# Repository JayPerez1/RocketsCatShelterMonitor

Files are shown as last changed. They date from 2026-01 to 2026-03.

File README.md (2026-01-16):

# Cat Shelter Monitor

Battery-powered temperature data logger to monitor temperatures and occupency in an outdoor feral cat shelter.

## Hardware (verified)
- Adafruit Feather nRF52840 Express
- DS3231 RTC + CR1220 backup
- 256KB SPI FRAM (CS = A1)
- 2x DS18B20 probes on 1-Wire (DATA = A2, external pull-up installed)
- 1S2P 18650 battery pack (not connected during bench testing)

## Firmware
- v1.0: Logging + BLE UART commands (STATUS / GETNEW / GETALL / CLEAR)

## Docs
- `docs/session-continuity.md`
- `docs/cat-shelter-chat-bootstrap.md`
- `docs/Cat_Shelter_BOM_v4.xlsx`

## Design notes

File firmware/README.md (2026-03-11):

# Cat Shelter Monitor Firmware

This folder contains firmware versions for the Cat Shelter Monitor project.

## Versions

### v1.1 – Current Development
Location:
firmware/CatShelterLogger_v1_1/

Features:
- BLE download support
- FRAM data logging
- RTC timestamping
- AMG8833 occupancy detection

### v1.0 – Legacy Version
Location:
firmware/CatShelterLogger_v1_0/

Earlier firmware used during early field testing.

## Hardware Platform

Board:
Adafruit nRF52840 Feather

Sensors:
- DS18B20 temperature sensors
- AMG8833 thermal array
- RTC
- FRAM

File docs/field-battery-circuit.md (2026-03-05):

# Cat Shelter Monitor — Field Battery Circuit (Final)

Battery packs are NOT charged in the field. Batteries are removed from the field enclosure,
charged in the office, and returned to the field.

The battery enclosure feeds the Feather through a 3 ft 2-wire cable into the Feather JST battery connector.

## Components inside battery enclosure

- 1-cell Li-ion battery
- Protection module (terminals: B+, B-, P+, P-)
- RUEF110 resettable PTC fuse (1.1A hold)
- On/Off switch
- 3 ft 22 AWG two-wire cable to Feather JST battery input

## Wiring

Battery → Protection board

Battery + → B+
Battery - → B-

Protected output → Feather

P+ → RUEF110 PTC → On/Off switch → Cable +
P- → Cable -

Cable + → JST +
Cable - → JST -

## Design Notes

- Protection board remains permanently connected to battery.
- Switch interrupts load only, not protection circuit.
- PTC fuse protects wiring and Feather from shorts.
- Cable shortened from 9 ft to 3 ft to reduce voltage drop.
- Wire gauge: 22 AWG.

## Field Check

Before connecting to the Feather:

Switch ON  
Measure voltage at JST connector

Red probe → JST +  
Black probe → JST -

Expected voltage: ~3.7–4.2 V

If voltage reads negative polarity is reversed.

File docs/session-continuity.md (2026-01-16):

# Session Continuity – Cat Shelter Monitor  
_Last updated: 2026-01-15_

## Project Overview
Battery-powered temperature data logger for an outdoor cat shelter.

- Logs **inside and outside temperature**
- Uses **FRAM for storage**
- **BLE download to phone**
- **CSV output**
- No field charging; batteries swapped indoors
- Target users are **non-technical**

---

## Hardware Status (COMPLETE & VERIFIED)

### Microcontroller
- Adafruit Feather nRF52840 Express

### Storage
- SPI FRAM 256KB
- CS pin: **A1**

### Timekeeping
- DS3231 RTC (I2C)
- CR1220 coin cell installed (RTC backup only)

### Sensors
- 2× DS18B20 waterproof probes
- Shared 1-Wire bus
- DATA pin: **A2**
- External pull-up resistor installed (DATA ? 3V)

### Power
- 1S2P 18650 battery pack
- Battery **not connected during bench testing**
- USB power verified
- Coin cell powers RTC only

### Wiring
- All wiring confirmed correct
- USB power test successful
- No electrical issues outstanding

---

## Software Status

### Firmware v1.0 (BASELINE – LOCKED)
- Logs temperature every **1 minute**
- Stores records in FRAM
- BLE UART commands:
  - `STATUS`
  - `GETNEW`
  - `GETALL`
  - `CLEAR`
- CSV format verified
- BLE + logging confirmed working end-to-end

### Known UX Issues in v1.0
- Generic BLE terminal required
- Manual copy/paste of scrolling text
- Buffer truncation in some apps
- Commands are non-intuitive for end users

These issues are **UX-related only**, not hardware or data integrity problems.

---

## GitHub / Version Control Status (IMPORTANT)

### Repository
- GitHub repo: `RocketsCatShelterMonitor`
- Remote correctly configured
- `main` branch is clean and synced

### Tags
- **v1.0** tag created and pushed  
  - Represents: *Hardware verified + original firmware behavior*

### Branching
- Active development branch:

---

## v1.1-ble-usability

- All future firmware changes must happen **only** on this branch

---

## Planned Improvements (v1.1 – NOT YET IMPLEMENTED)

Chosen improvement strategy:
- **Path 1 + Path 2**
- Self-guided BLE output
- Chunked CSV transfer

### v1.1 Design Goals
- Auto status/help text on BLE connect
- Replace multiple commands with a single user-facing command:

---

## Download

- Send **pure CSV only**
- Chunk output to avoid buffer overruns
- End with a clear marker:

---

## DOWNLOAD_COMPLETE,<sent>,<remaining>

- Keep logging interval at 1 minute
- Preserve all existing pin assignments

### Important Constraint
User is **not a programmer**.  
Any future code changes must be:
- One complete file
- Copy/paste only
- Exact file locations specified
- Step-by-step instructions, no assumptions

---

## Where to Resume Next Session

### First action tomorrow
1. Open this repository
2. Confirm you are on branch:

---

## v1.1-ble-usability

3. Provide the **current firmware HELP or STATUS output**
so the v1.1 code can be generated without guessing

### Next milestone
- Create `CatShelterLogger_v1_1.ino`
- Implement BLE usability improvements
- Commit as first v1.1 change
- Keep v1.0 untouched and recoverable

---

## Current State Summary
- Hardware: ? complete
- Firmware v1.0: ? working, tagged
- GitHub: ? clean, synced, recoverable
- UX improvements: ? planned, not yet started

Project is stable and ready to continue.

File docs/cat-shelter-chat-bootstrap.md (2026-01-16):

?? Session Continuity Summary – Outdoor Cat Shelter Monitoring Project
Project Goal

Build a battery-powered data logger to monitor inside and outside temperature of a stationary outdoor cat shelter, with phone-based data download and no field charging.

Locked Design Decisions
Power

Battery system: 1S2P using two 18650 cells (3.0–4.2 V)

Charging: Indoors only

Field unit: No charging circuitry

Batteries are swapped, not charged in the enclosure

USB port used only for programming/debug

Data & Operation

Logs temperature data continuously

Must store at least 7–10 days of data

Uses external FRAM for storage

BLE data download required from day one

Phone downloads only new data since last offload

Data saved as CSV, plain text

Sensors

2× waterproof DS18B20 temperature probes

One inside shelter

One outside shelter

Direct wiring (no JST/STEMMA requirement)

Environment

Northeast U.S. climate

Components sheltered from direct weather exposure

User Constraints

User is not a programmer

All instructions must be:

Exact step-by-step

No explanations unless explicitly requested

Any code must be:

Fully written

Exact cut-and-paste

With explicit file locations

BOM Rules

Adafruit first, Mouser second

Direct product URLs only

Plain Excel BOM

No formulas

No formatting

Raw values only

Final Hardware Selected (Prototype)
Microcontroller

Adafruit Feather nRF52840 Express (PID 4062)

BLE-first

No Wi-Fi required

Chosen specifically for reliable phone BLE downloads

Storage

Adafruit SPI FRAM 256KB (PID 4718)

Timekeeping

DS3231 RTC breakout (PID 3013)

CR1220 backup battery (PID 380)

Temperature Sensors

2× Adafruit waterproof DS18B20 probes (PID 381)

Includes required pull-up resistor

Power / Wiring

Switched JST-PH breakout (PID 1863)

Silicone ribbon cable (PID 6181)

User already has:

18650 batteries

Chargers

Heat shrink

Misc. connectors

Current Status

All prototype parts have been ordered from Adafruit

No assembly or software steps have been performed yet

Waiting for parts to arrive

Next Planned Steps (After Parts Arrive)

Inventory check

Exact wiring steps (one wire at a time)

Exact software installation steps

Firmware upload (provided fully written)

First power-on verification

BLE download test to phone

CSV file verification

Possible Interim Step (Optional, Before Parts Arrive)

Create a Git repository to:

Organize firmware

Store BOM and documentation

Back up project state

End of summary.

When you’re ready:

Start a new chat

Paste everything above

Say either:

“Parts arrived”, or

“Let’s set up the Git repo first”

We’ll pick up cleanly from there.

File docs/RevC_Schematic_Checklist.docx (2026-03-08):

Cat Shelter Monitor

Carrier Board Rev C — KiCAD Schematic Change Checklist

AMG8833 Thermal Camera Occupancy Sensor Addition

# Overview

This checklist documents all KiCAD schematic changes required to upgrade the Cat Shelter Monitor carrier board from Rev B to Rev C. The primary change is the addition of the Adafruit AMG8833 8x8 thermal camera sensor for cat occupancy detection.

The AMG8833 communicates via I2C and shares the existing I2C bus with the DS3231 RTC. The sensor will be mounted in a separate external enclosure connected via a STEMMA QT cable (JST-SH 4-pin 1.0mm) up to 24 inches in length.

## I2C Address Conflict Check

Confirm the following addresses are compatible before proceeding:

Device | I2C Address | Notes
DS3231 RTC | 0x68 | Fixed address.
AMG8833 Thermal Camera | 0x69 (default) | Can be changed to 0x68 by soldering Addr jumper — leave open (0x69).

- IMPORTANT: Do not solder the Addr jumper on the AMG8833 breakout board. Leave it open to maintain address 0x69.

# New Components to Add

Ref Des | Component | Value / Part | Notes
J_AMG1 | JST-SH 4-pin 1.0mm connector | JST SM04B-SRSS-TB or equivalent | STEMMA QT cable mates here. Bottom strip only — top strip is mechanical.

- The JST-SH connector pinout (looking into connector): pin 1 = GND, pin 2 = VCC, pin 3 = SDA, pin 4 = SCL on standard STEMMA QT cables. Verify against your specific cable before wiring.

# New Net Labels and Connections

Net Label | From | To | Notes
I2C_SDA | J_FEATHER_L1 (SDA pin) | J_AMG1 pin 4 | Shared with DS3231 RTC. No conflict — different I2C addresses.
I2C_SCL | J_FEATHER_L1 (SCL pin) | J_AMG1 pin 3 | Shared with DS3231 RTC. No conflict — different I2C addresses.
+3V3 | Feather 3V rail | J_AMG1 pin 1 | AMG8833 breakout has onboard 3.3V regulator. Feed 3.3V from Feather directly.
GND | Ground plane | J_AMG1 pin 2 | Common ground.
AMG_INT_D9 | J_AMG1 pin 5 (INT) | J_FEATHER_R1 (D9 pin) | Active low interrupt from AMG8833. D9 configured INPUT_PULLUP in firmware.

# Verification Checklist

Complete each item in order before sending the board for fabrication.

# | Check | Expected Result

1 | J_AMG1 connector added to schematic | JST-SH 4-pin 1.0mm, labeled J_AMG1
2 | J_AMG1 pin 1 connected to +3V3 net | Power to AMG8833 VIN
3 | J_AMG1 pin 2 connected to GND net | Common ground
4 | J_AMG1 pin 3 connected to I2C_SCL net | Shared SCL bus
5 | J_AMG1 pin 4 connected to I2C_SDA net | Shared SDA bus
6 | J_AMG1 pin 5 connected to AMG_INT_D9 net | INT signal from sensor
7 | AMG_INT_D9 net routed to J_FEATHER_R1 D9 pin | Interrupt to Feather
8 | AMG_INT_D9 label applied at both ends of net | Consistent net naming
9 | DS3231 I2C address confirmed 0x68 | No address conflict with AMG8833 at 0x69
10 | AMG8833 Addr jumper confirmed unsoldered | AMG8833 at 0x69
11 | Run ERC in KiCAD — no new errors | Clean ERC pass
12 | Run netlist check — all new nets connected | No unconnected pins on J_AMG1
13 | Update schematic title block to Rev C | Revision history reflects changes
14 | Add J_AMG1 to BOM | Component captured for procurement

# Associated Firmware Changes

The following firmware changes have already been implemented in CatShelterLogger_v1_2.ino and platformio.ini. They are noted here for reference only — no additional firmware work is required before fabrication.

- Added adafruit/Adafruit AMG88xx@^1 to platformio.ini lib_deps
- AMG8833 initialized on I2C in setup()
- D9 configured as INPUT_PULLUP for INT pin
- Occupancy detection: pixel deviation from scene average in either direction (handles hot cat in cool shelter and cool cat in hot shelter)
- Cat count estimation via flood-fill blob detection on 8x8 pixel grid
- Rate-of-Rise (RoR) calculation on internal DS18B20 probe — 4-sample rolling window
- Two-factor occupancy: OR logic during testing (change to AND after threshold tuning)
- Pixel stats (min, max, avg) stored in each CSV record for post-analysis
- New THERMAL BLE command for real-time raw pixel dump during field tuning
- Updated Record struct — MAGIC bumped to prevent v1.1 FRAM data misread
- Updated CSV header: datetime, t0C, t1C, occupied, cats, pix_min, pix_max, pix_avg

# Field Tuning Notes

The following compile-time constants in CatShelterLogger_v1_2.ino will require tuning based on real-world testing. Use the THERMAL BLE command to observe raw pixel values before adjusting.

- AMG_DEVIATION_THRESHOLD (default 4.0°C) — minimum pixel deviation from scene average to be considered a hot/cold spot
- AMG_MIN_BLOB_PIXELS (default 3) — minimum connected pixels to count as one cat
- ROR_THRESHOLD_C_PER_MIN (default 0.5°C/min) — rate of rise threshold on internal probe
- ROR_WINDOW_SIZE (default 4 samples) — at 30s interval = 2 min history; at 3min interval = 12 min history — may need reducing for deployed interval
- After initial tuning, change occupancy detection logic from OR to AND in detectOccupancy() for reduced false positives.

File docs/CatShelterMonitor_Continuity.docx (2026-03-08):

Rockets Cat Shelter Monitor

Project Continuity Document

Generated: March 2026

GitHub: https://github.com/JayPerez1/RocketsCatShelterMonitor

Purpose: Provide full project context to resume work in a future AI session or hand off to another developer.

# 1. Project Overview

The Rockets Cat Shelter Monitor is a battery-powered IoT system for monitoring feral cat shelters in urban and suburban backyards in the Northeast USA. The system collects temperature and occupancy data, stores it locally, and transfers it to a mobile phone via Bluetooth Low Energy (BLE) for export as CSV/Excel.

The project is organized in two phases:

- Phase 1 (complete): Temperature monitoring using two DS18B20 waterproof probes — one inside, one outside the shelter.
- Phase 2 (in progress): Occupancy detection using an AMG8833 8x8 thermal camera sensor, with Rate-of-Rise compensation to reduce false positives.

Deployment environment: 2'x2'x1.5' insulated wood and dense foam shelters, single entry point, no WiFi, no solar power, northeast USA.

# 2. Hardware

Component | Part # | Status | Notes
Adafruit Feather nRF52840 | #4062 | In use | Main MCU. nRF52840, BLE, 1MB Flash, 256KB RAM, 64MHz Cortex-M4.
DS18B20 Waterproof Temp Sensor (x2) | #381 | In use | One-Wire bus on pin A2. 4.7kΩ pull-up. Probe 0 = inside shelter, Probe 1 = outside.
Adafruit FRAM SPI | — | NOT working — Rev A/B PCB error | Corrected in Rev B KiCAD schematic. CS on D10.
DS3231 RTC | — | NOT working — Rev A/B PCB error | Corrected in Rev B KiCAD schematic. I2C address 0x68.
Adafruit AMG8833 8x8 Thermal Camera | #3538 (STEMMA QT) | PLANNED — Rev C | I2C address 0x69. INT on D9. External enclosure, 18-24" STEMMA QT cable.
18650 Li-Ion Cell (x1) | — | In use | 5+ day battery life tested.
Custom Carrier PCB | Rev B (corrected, not fabricated) | PENDING fabrication | Rev C will incorporate AMG8833 connector.

## 2.1 Pin Assignments

Pin | Net / Signal | Connected To
A2 | A2_1WIRE | DS18B20 One-Wire bus (both probes). 4.7kΩ pull-up to 3.3V.
D10 | FRAM_CS_D10 | FRAM SPI chip select.
SCK | SPI_SCK | FRAM SPI clock.
MO | SPI_MOSI | FRAM SPI MOSI.
MI | SPI_MISO | FRAM SPI MISO.
SDA | I2C_SDA | DS3231 RTC (0x68). AMG8833 thermal camera (0x69) — Rev C.
SCL | I2C_SCL | DS3231 RTC (0x68). AMG8833 thermal camera (0x69) — Rev C.
D9 | AMG_INT_D9 | AMG8833 INT pin (active low). Configured INPUT_PULLUP in firmware. — Rev C.
A0, A1, A3, A4, A5, D5, D6, D11, D12, D13, D2 | Available | Unconnected. Available for future use.

## 2.2 I2C Bus

- DS3231 RTC: address 0x68
- AMG8833 Thermal Camera: address 0x69 (default — Addr jumper must remain unsoldered)
- No address conflict. Both devices share SDA/SCL.
- Cable to AMG8833: 18-24" STEMMA QT (JST-SH 4-pin 1.0mm). I2C at 100kHz over this length requires testing and may need pull-up tuning.

## 2.3 PCB Status

- Rev A: Original fabricated board. FRAM and RTC had wiring errors — non-functional.
- Rev B: Corrections made in KiCAD schematic. Not yet fabricated.
- Rev C: Rev B corrections + AMG8833 JST-SH connector + AMG_INT_D9 net. Target for fabrication. See RevC_Schematic_Checklist.docx for full change list.

# 3. Firmware

File | Version | Notes
CatShelterLogger_v1_1.ino | v1.1 | Phase 1 — temperature only. Currently deployed. Saved to GitHub before v1.2 changes.
CatShelterLogger_v1_2.ino | v1.2 | Phase 2 — adds AMG8833 occupancy detection, RoR, THERMAL BLE command. PENDING hardware.
platformio.ini | v1.2 | Adds adafruit/Adafruit AMG88xx@^1 to lib_deps.

## 3.1 Key Architecture Decisions

- Framework: Arduino via PlatformIO.
- Storage: FRAM primary (when working). RAM-only fallback when FRAM unavailable — currently active since FRAM not yet functional on Rev A/B hardware.
- Time base: Set via SETUNIX BLE command from phone. RTC not yet functional — firmware maintains soft clock from phone-set Unix timestamp.
- BLE: Nordic UART Service (NUS) via Adafruit Bluefruit library. Device name 'CatSh'. Self-guides user with welcome banner and HELP command on connect.
- CSV download: Chunked with small delays (3ms per line, 20ms yield every 25 lines) to avoid BLE buffer overflow.

## 3.2 BLE Commands

Command | Version | Description
HELP | v1.1+ | Lists all available commands.
STATUS | v1.1+ | Reports firmware build, write_index, last_sent_index, max_records, record size, fram_ok, rtc_ok, ram_only, amg_ok, current RoR, RoR sample count.
SETUNIX <unix_seconds> | v1.1+ | Sets the time base from phone Unix timestamp. Used since RTC is not yet working.
DOWNLOAD | v1.1+ | Downloads CSV records since last_sent_index. Updates last_sent_index on completion.
DOWNLOADALL | v1.1+ | Downloads all CSV records from index 0.
THERMAL | v1.2 | Dumps current 8x8 AMG8833 pixel array. Reports scene avg, min, max, current RoR, then rows R0-R7. Use for field tuning of threshold constants.
CLEAR | v1.1+ | Resets write_index and last_sent_index. Clears RoR window in v1.2.

## 3.3 CSV Output Format (v1.2)

Column | Version | Description
datetime | v1.1+ | MM/DD HH:MM. UTC-5 (EST). No DST adjustment.
t0C | v1.1+ | Inside shelter temperature in °C (rounded integer).
t1C | v1.1+ | Outside shelter temperature in °C (rounded integer).
occupied | v1.2 | 0 = unoccupied, 1 = occupied. Two-factor: thermal blob OR RoR trigger (change to AND after tuning).
cats | v1.2 | Estimated cat count 0-4 from blob detection.
pix_min | v1.2 | Minimum pixel temperature in °C from AMG8833 frame.
pix_max | v1.2 | Maximum pixel temperature in °C from AMG8833 frame.
pix_avg | v1.2 | Average pixel temperature in °C from AMG8833 frame.

## 3.4 Occupancy Detection Algorithm

The algorithm uses two independent factors combined with OR logic during initial testing (to be changed to AND after tuning):

Factor 1 — Thermal Blob Detection (AMG8833):

- Read all 64 pixels from the 8x8 array.
- Calculate scene average temperature.
- Flag pixels that deviate from the average by more than AMG_DEVIATION_THRESHOLD in either direction. This handles both cool-weather scenarios (cat warmer than shelter) and summer scenarios (cat cooler than hot shelter interior).
- Use 4-connectivity flood fill to identify connected blobs of deviant pixels.
- Blobs smaller than AMG_MIN_BLOB_PIXELS are discarded as noise.
- Remaining blob count = estimated cat count (capped at AMG_MAX_CATS).

Factor 2 — Rate-of-Rise on Internal Probe (DS18B20 probe 0):

- Maintain a rolling window of ROR_WINDOW_SIZE temperature samples.
- Calculate RoR = (newest - oldest) / time_span in °C/minute.
- Absolute value is used — handles both warming entry and cooling entry into hot summer shelter.
- If |RoR| exceeds ROR_THRESHOLD_C_PER_MIN, it indicates animal entry event.
- Slow solar heating of insulated shelter produces drift well below this threshold. Analogous to commercial RoR fire detectors used in attics.

## 3.5 Tuning Constants

All tuning constants are compile-time defines at the top of CatShelterLogger_v1_2.ino. Use the THERMAL BLE command to observe real field values before adjusting.

Constant | Default | Notes
AMG_DEVIATION_THRESHOLD | 4.0°C | Minimum pixel deviation from scene average (either direction) to flag as hot/cold spot. Handles both cool-weather and summer scenarios.
AMG_MIN_BLOB_PIXELS | 3 pixels | Minimum connected pixels to count as one cat blob.
AMG_MAX_CATS | 4 | Maximum reported cat count.
ROR_WINDOW_SIZE | 4 samples | Rolling window for RoR calculation. At 30s interval = 2 min history. At 3min deployed interval = 12 min — may need reducing.
ROR_THRESHOLD_C_PER_MIN | 0.5°C/min | Absolute RoR threshold on internal probe. Handles both entry (warming) and entry-into-hot-shelter (cooling).
LOG_INTERVAL_MS | 30,000ms | 30 seconds for dev/test. Change to 180,000ms (3 min) for deployment.

# 4. Key Design Decisions and Rationale

Decision | Rationale
AMG8833 thermal camera selected over PIR, IR beam break, VL53L0X ToF | PIR detects only motion, not stationary sleeping cats. IR beam break only detects entry/exit. VL53L0X detects entry only. AMG8833 can detect stationary presence and estimate multiple occupants via blob detection.
STEMMA QT version of AMG8833 selected | JST-SH 4-pin keyed connector eliminates wiring errors on 18-24" cable run. No soldering required on sensor side.
D9 selected for AMG8833 INT pin | Not currently used in schematic. No documented restrictions on nRF52840 Feather. Supports interrupts. D2 is restricted (NFC pad). D7 is onboard tactile switch. D3 is onboard red LED.
Rate-of-Rise (RoR) on internal DS18B20 added as second occupancy factor | Insulated shelter changes temperature slowly due to environmental factors. Animal entry causes rapid change. RoR is direction-agnostic — handles both cool-weather entry (warming) and summer entry (cooling). Analogous to commercial fire alarm RoR detectors in attics.
OR logic for occupancy during initial testing | Allows independent observation of both thermal blob detection and RoR in CSV data before committing to AND logic. Change to AND after threshold tuning is complete.
Pixel stats (min, max, avg) stored in every record | Provides historical context for post-analysis without requiring a live BLE connection. Enables algorithm performance review from downloaded CSV.
THERMAL BLE command added | Allows real-time observation of raw 8x8 pixel values in the field. Essential for informed threshold tuning rather than guessing.
Record MAGIC bumped to CSLH for v1.2 | Record struct size changed (new fields added). Different MAGIC prevents v1.1 FRAM data from being misread as valid v1.2 data.
I2C shared bus for RTC and AMG8833 | DS3231 at 0x68, AMG8833 at 0x69 — no address conflict. AMG8833 Addr jumper must remain unsoldered. I2C cable length up to 24" at 100kHz requires testing.

# 5. Open Items and Next Steps

Items are listed in recommended sequence. Items 4 and 10 have no dependencies and can be done immediately.

# | Item | Detail | Dependency

1 | Fabricate Rev C carrier PCB | Incorporate all Rev B corrections plus AMG8833 JST-SH connector and AMG_INT_D9 net. See RevC_Schematic_Checklist.docx. | KiCAD schematic Rev C complete
2 | Verify STEMMA QT cable pinout | Confirm pin 1 orientation on the specific cable purchased before PCB layout is finalized. | Cable selection
3 | Test I2C reliability over 18-24" cable | At 100kHz. May require pull-up resistor tuning based on cable capacitance. Test before committing to cable length. | Rev C hardware
4 | Prototype AMG8833 on breadboard | Wire to Feather via breadboard before Rev C PCB arrives. Verify sensor reads correctly and THERMAL BLE command works. | None — can do now
5 | Field-tune occupancy thresholds | Use THERMAL BLE command to observe real pixel values. Adjust AMG_DEVIATION_THRESHOLD, AMG_MIN_BLOB_PIXELS, ROR_THRESHOLD_C_PER_MIN, ROR_WINDOW_SIZE. | Prototype working
6 | Switch occupancy logic from OR to AND | In detectOccupancy() — line marked with comment. Do this after thresholds are tuned and false positive rate is acceptable. | Field tuning complete
7 | Verify FRAM and RTC on Rev C board | Both were non-functional on Rev A/B due to PCB errors. Rev B corrections are in KiCAD but untested on physical hardware. | Rev C hardware
8 | Adjust LOG_INTERVAL_MS for deployment | Change from 30,000ms (30s) to 180,000ms (3 min) in firmware. Also re-evaluate ROR_WINDOW_SIZE at 3-min interval. | Field testing
9 | DST handling in CSV timestamps | Current firmware applies fixed UTC-5 offset (EST). No DST adjustment. Consider adding DST handling for spring/summer accuracy. | Optional enhancement
10 | Update GitHub after Rev C firmware changes | Save v1.2 firmware and updated platformio.ini to GitHub. Repository: https://github.com/JayPerez1/RocketsCatShelterMonitor | None — do before hardware work

# 6. Repository and File Reference

## 6.1 GitHub

- URL: https://github.com/JayPerez1/RocketsCatShelterMonitor
- State at session end: v1.1 firmware and existing files saved to GitHub before v1.2 changes were written.
- Next commit should include: CatShelterLogger_v1_2.ino and updated platformio.ini.

## 6.2 Key Files

- CatShelterLogger_v1_1.ino — Phase 1 firmware (temperature only). Baseline.
- CatShelterLogger_v1_2.ino — Phase 2 firmware (occupancy detection). Written but not yet deployed to hardware.
- platformio.ini — Build configuration. v1.2 adds Adafruit AMG88xx library.
- CatShelterMonitor_Carrier-RevB.kicad_sch — Corrected schematic (Rev B). Not yet fabricated. Basis for Rev C.
- RevC_Schematic_Checklist.docx — Complete checklist of KiCAD changes required for Rev C PCB.

## 6.3 Uploaded Reference Documents (from this session)

- adafruit-amg8833-8x8-thermal-camera-sensor.pdf — Adafruit AMG8833 learn guide. Confirms I2C address 0x69, pinout, library name, 10K pull-ups on breakout board.
- introducing-the-adafruit-nrf52840-feather.pdf — Feather nRF52840 guide. Confirms D9 has no restrictions. D2 is NFC pad (avoid). D7 is tactile switch. D3 is red LED.

# 7. How to Resume in a New AI Session

To bring a new AI assistant up to speed quickly, provide the following in order:

- Share this document.
- Share RevC_Schematic_Checklist.docx.
- Upload CatShelterLogger_v1_2.ino and platformio.ini.
- Upload CatShelterMonitor_Carrier-RevB.kicad_sch if schematic work is needed.
- State which open item from Section 5 you want to work on next.

The AI will not need the full chat transcript if this document is provided. All critical decisions, rationale, hardware details, firmware architecture, and open items are captured here.

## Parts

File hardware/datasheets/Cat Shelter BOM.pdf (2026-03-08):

Sort | Item | Category | Supplier | Supplier SKU | Manufacturer | MPN | Buy Qty | Buy Price | Need Qty | Per Unit | Ext. Price
1 | Microcontroller board (BLE-first) | Compute | Adafruit | 4062 | Adafruit Industries | 4062 | 1 | $24.95 | 1 | $24.95 | $24.95
2 | Non-volatile memory (SPI FRAM 256KB) | Data Storage | Adafruit | 4718 | Fujitsu | MB85RS2MTA | 1 | $12.95 | 1 | $12.95 | $12.95
3 | Precision RTC breakout (I2C) | Timekeeping | Adafruit | 3013 | Analog Devices / Maxim | DS3231 | 1 | $17.50 | 1 | $17.50 | $17.50
4 | Coin cell for RTC backup | Timekeeping | Adafruit | 380 | Various (verified by Adafruit) CR1220 | | 1 | $0.95 | 1 | $0.95 | $0.95
5 | Waterproof temperature probe (DS18B20) | Sensing | Adafruit | 381 | Maxim / Analog Devices | DS18B20 | 1 | $9.95 | 2 | $9.95 | $19.90
6 | AMG8833 IR Thermal Camera | Sensing | Adafruit | 3538 | Adafruit Industries | 3538 | 1 | $44.95 | 1 | $44.95 | $44.95
7 | Custom Circuit Board v1.0 (Protoype) | Circuit Board | OSH Park | aE27EfQZ | OSH Park | | 3 | $49.25 | 1 | $16.42 | $16.42
7 | Custom Circuit Board v2.0 (Add Camera) | Circuit Board | OSH Park | KNqJMJn5 | OSH Park | | 3 | $59.25 | 0 | $19.75 | $0.00
8 | CABLE ASSY JST PH 2 PIN 4" | Circuit Board | DigiKey | 1528-261-ND | Adafruit Industries | 261 | 2 | $1.50 | 2 | $0.75 | $1.50
9 | 3W, 3.5MM PITCH TERM-BLOCK, ANGLED | Circuit Board | DigiKey2073-TBD05-03-1-G-G-NDGCT | | | TBD05-03-1-G-G | 10 | $8.84 | 2 | $0.88 | $1.77
10 | PTC RESET FUSE 30V 1.1A RADIAL | Circuit Board | DigiKey | RUEF110HF-ND | Littelfuse Inc. | RUEF110 | 5 | $2.00 | 1 | $0.40 | $0.40
11 | 18650 Lithium-Ion Battery | Power | | | | | 1 | $0.00 | 1 | $0.00 | $0.00
12 | 18650 Lithium-Ion Battery Holder | Power (Outdoor) | Amazon | B09LC681XX | Aobao | AB- Battery Holder | 5 | $10.79 | 1 | $2.16 | $2.16
13 | Litium-Ion BMS Protection Board | Power (Outdoor) | eBay | | ovo-trend-seller | | 5 | $14.34 | 1 | $2.87 | $2.87
14 | Mini Rocker Switch | Power (Outdoor) | eBayKG-15mm-HX15cm-2P-Hei-5 YuanXing | | | | 5 | $11.61 | 1 | $2.32 | $2.32
15 | ATO blade fuse, 2A | Power (Outdoor) | Mouser | 576-0ATO002.V | Littelfuse | 0ATO002.V | 5 | $1.24 | 1 | $0.25 | $0.25
16 | PG-7 Cable Glands | Enclosure | eBay | 225FWY | | | 10 | $11.87 | 5 | $1.19 | $5.94
17 | 22 AWG Silicone Wire - 20ft (Black & Red) | Wiring | eBay | | | | 20 | $9.22 | 10 | $0.46 | $4.61
18 | Break-Away Male Header Strip | Prototyping | Amazon | 16P16-2.54-30 | Antrader | B07GP3TLH9 | 30 | $7.55 | 4 | $0.25 | $1.01
19 | Circuit Board Enclosure | Consumables | 3D Printer | | | | 3 | $3.00 | 1 | $1.00 | $1.00
20 | Charger Station Enclosure | Consumables | 3D Printer | | | | 3 | $3.00 | 1 | $1.00 | $1.00
21 | Field Battery Enclosure | Consumables | 3D Printer | | | | 3 | $3.00 | 1 | $1.00 | $1.00
22 | Infrared Camera Enclosure | Consumables | 3D Printer | | | | 1 | $1.00 | 1 | $1.00 | $1.00
23 | Multi-colored heat shrink pack | Consumables | Adafruit | 1649 | Adafruit Industries | 1649 | 1 | $4.95 | 1 | $4.95 | $4.95
24 | UPS Ground | Shipping | UPS | | | | | $35.00 | | | $25.00
Total Amount Spent | $348.66 | $194.38
Amount in Inventory | $154.28

8 | USB-C LiIon/LiPoly charger (desk charger) | Power (Indoor) | Adafruit | 4410 | Adafruit Industries | 4410 | 5 | $5.95 | 0 | $1.19 | $0.00
| 3W, 3.5MM PITCH TERM-BLOCK, SIDE | Circuit Board | DigiKey | -TAD05-03-1-L-G-ND | | TAD05-03-1-L-G | 1 | $0.43 | 0 | $0.43 | $0.00

Direct Product URL | Status | Lead/Risk Notes
https://www.adafruit.com/product/4062 | Required | BLE required; Micro-USB for programming.
https://www.adafruit.com/product/4718 | Recommended | 256KB FRAM provides weeks of logs.
https://www.adafruit.com/product/3013 | Recommended | Add CR1220 backup battery for time retention.
https://www.adafruit.com/product/380 | Recommended | Lithium shipping restrictions may apply.
https://www.adafruit.com/product/381 | Required | Waterproof probe; Includes 4.7k pull-up resistor.
https://www.adafruit.com/product/6181 | Required
https://oshpark.com/orders/KNqJMJn5 | Required
https://oshpark.com/orders/KNqJMJn5 | Required
https://www.digikey.com/en/products/detail/adafruit-industries-llc/261/5353586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 Required https://www.digikey.com/en/products/detail/gct/TBD05-03-1-G-G/26408887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 Required
| Required | Recovered from Ryobi 40v, 6amp Battery Pack.
https://www.amazon.com/dp/B09LC681XX?ref=ppx_yo2ov_dt_b_fed_asin_title | Required
ovo-trend-seller | Required
5Pcs Mini round Rocker Switch 15Mm on off Latching Toggle Switch SPST 2Pin 6A 12 | eBay | Required
https://www.mouser.com/ProductDetail/Littelfuse/0ATO002.V | Required | Spare fuses recommended.
https://www.ebay.com/itm/222447428743 | Required | Sized for 0.118"–0.169" cable diameter.
https://www.ebay.com/itm/198037457213 | Required | Flexible in cold; good for internal harnessing.
https://www.amazon.com/dp/B07GP3TLH9?ref=ppx_yo2ov_dt_b_fed_asin_title&th=1 | Required | 2.54mm 16 Pin Single Row PBC Female Pin Header.
https://www.adafruit.com/product/1649 | Recommended | Strain relief + labeling.
Shipping UPS Ground | Required
Total for 1st Board

https://www.adafruit.com/product/4410 | Required | Used indoors only.

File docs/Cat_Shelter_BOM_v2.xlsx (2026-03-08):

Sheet: BOM
Sort | Item | Category | Supplier | Supplier SKU | Manufacturer | MPN | Buy Qty | Buy Price | Need Qty | Per Unit | Ext. Price | Direct Product URL | Status | Lead/Risk Notes
1 | Microcontroller board (BLE-first) | Compute | Adafruit | 4062 | Adafruit Industries | 4062 | 1 | $24.95 | 1 | $24.95 | $24.95 | https://www.adafruit.com/product/4062 | Required | BLE required; Micro-USB for programming.
2 | Non-volatile memory (SPI FRAM 256KB) | Data Storage | Adafruit | 4718 | Fujitsu | MB85RS2MTA | 1 | $12.95 | 1 | $12.95 | $12.95 | https://www.adafruit.com/product/4718 | Recommended | 256KB FRAM provides weeks of logs.
3 | Precision RTC breakout (I2C) | Timekeeping | Adafruit | 3013 | Analog Devices / Maxim | DS3231 | 1 | $17.50 | 1 | $17.50 | $17.50 | https://www.adafruit.com/product/3013 | Recommended | Add CR1220 backup battery for time retention.
4 | Coin cell for RTC backup | Timekeeping | Adafruit | 380 | Various (verified by Adafruit) | CR1220 | 1 | $0.95 | 1 | $0.95 | $0.95 | https://www.adafruit.com/product/380 | Recommended | Lithium shipping restrictions may apply.
5 | Waterproof temperature probe (DS18B20) | Sensing | Adafruit | 381 | Maxim / Analog Devices | DS18B20 | 1 | $9.95 | 2 | $9.95 | $19.90 | https://www.adafruit.com/product/381 | Required | Waterproof probe; Includes 4.7k pull-up resistor.
6 | AMG8833 IR Thermal Camera | Sensing | Adafruit | 3538 | Adafruit Industries | 3538 | 1 | $44.95 | 1 | $44.95 | $44.95 | https://www.adafruit.com/product/6181 | Required
7 | Custom Circuit Board v1.0 (Protoype) | Circuit Board | OSH Park | aE27EfQZ | OSH Park |  | 3 | $49.25 | 1 | $16.42 | $16.42 | https://oshpark.com/orders/KNqJMJn5 | Required
7 | Custom Circuit Board v2.0 (Add Camera) | Circuit Board | OSH Park | KNqJMJn5 | OSH Park |  | 3 | $59.25 | 0 | $19.75 | $0.00 | https://oshpark.com/orders/KNqJMJn5 | Required
8 | CABLE ASSY JST PH 2 PIN 4" | Circuit Board | DigiKey | ‎1528-261-ND‎ | Adafruit Industries | 261‎ | 2 | $1.50 | 2 | $0.75 | $1.50 | https://www.digikey.com/en/products/detail/adafruit-industries-llc/261/5353586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 | Required
9 | 3W, 3.5MM PITCH TERM-BLOCK, ANGLED | Circuit Board | DigiKey | 2073-TBD05-03-1-G-G-ND | GCT | ‎TBD05-03-1-G-G‎ | 10 | $8.84 | 2 | $0.88 | $1.77 | https://www.digikey.com/en/products/detail/gct/TBD05-03-1-G-G/26408887?_gl=1*hqzd1z*_up*MQ..&gclsrc=3p.ds | Required
10 | PTC RESET FUSE 30V 1.1A RADIAL | Circuit Board | DigiKey | ‎RUEF110HF-ND‎ | Littelfuse Inc. | RUEF110‎ | 5 | $2.00 | 1 | $0.40 | $0.40
11 | 18650 Lithium-Ion Battery | Power |  |  |  |  | 1 | $0.00 | 1 | $0.00 | $0.00 |  | Required | Recovered from Ryobi 40v, 6amp Battery Pack.
12 | 18650 Lithium-Ion Battery Holder | Power (Outdoor) | Amazon | B09LC681XX | Aobao | AB- Battery Holder | 5 | $10.79 | 1 | $2.16 | $2.16 | https://www.amazon.com/dp/B09LC681XX?ref=ppx_yo2ov_dt_b_fed_asin_title | Required
13 | Litium-Ion BMS Protection Board | Power (Outdoor) | eBay |  | ovo-trend-seller |  | 5 | $14.34 | 1 | $2.87 | $2.87 | ovo-trend-seller | Required
14 | Mini Rocker Switch | Power (Outdoor) | eBay | KG-15mm-HX15cm-2P-Hei-5 | YuanXing |  | 5 | $11.61 | 1 | $2.32 | $2.32 | 5Pcs Mini round Rocker Switch 15Mm on off Latching Toggle Switch SPST 2Pin 6A 12 | eBay (https://www.ebay.com/itm/226886814060) | Required
15 | ATO blade fuse, 2A | Power (Outdoor) | Mouser | 576-0ATO002.V | Littelfuse | 0ATO002.V | 5 | $1.24 | 1 | $0.25 | $0.25 | https://www.mouser.com/ProductDetail/Littelfuse/0ATO002.V | Required | Spare fuses recommended.
16 | PG-7 Cable Glands | Enclosure | eBay | 225FWY |  |  | 10 | $11.87 | 5 | $1.19 | $5.93 | https://www.ebay.com/itm/222447428743 | Required | Sized for 0.118"–0.169" cable diameter.
17 | 22 AWG Silicone Wire - 20ft (Black & Red) | Wiring | eBay |  |  |  | 20 | $9.22 | 10 | $0.46 | $4.61 | https://www.ebay.com/itm/198037457213 | Required | Flexible in cold; good for internal harnessing.
18 | Break-Away Male Header Strip | Prototyping | Amazon | 16P16-2.54-30 | Antrader | B07GP3TLH9 | 30 | $7.55 | 4 | $0.25 | $1.01 | https://www.amazon.com/dp/B07GP3TLH9?ref=ppx_yo2ov_dt_b_fed_asin_title&th=1 | Required | 2.54mm 16 Pin Single Row PBC Female Pin Header.
19 | Circuit Board Enclosure | Consumables | 3D Printer |  |  |  | 3 | $3.00 | 1 | $1.00 | $1.00
20 | Charger Station Enclosure | Consumables | 3D Printer |  |  |  | 3 | $3.00 | 1 | $1.00 | $1.00
21 | Field Battery Enclosure | Consumables | 3D Printer |  |  |  | 3 | $3.00 | 1 | $1.00 | $1.00
22 | Infrared Camera Enclosure | Consumables | 3D Printer |  |  |  | 1 | $1.00 | 1 | $1.00 | $1.00
23 | Multi-colored heat shrink pack | Consumables | Adafruit | 1649 | Adafruit Industries | 1649 | 1 | $4.95 | 1 | $4.95 | $4.95 | https://www.adafruit.com/product/1649 | Recommended | Strain relief + labeling.
24 | UPS Ground | Shipping | UPS |  |  |  |  | $35.00 |  |  | $25.00 | Shipping UPS Ground | Required
 |  |  |  |  |  |  | Total Amount Spent | $348.66 |  |  | $194.38 | Total for 1st Board
 |  |  |  |  |  |  | Amount in Inventory | $154.28
8 | USB-C LiIon/LiPoly charger (desk charger) | Power (Indoor) | Adafruit | 4410 | Adafruit Industries | 4410 | 5 | $5.95 | 0 | $1.19 | $0.00 | https://www.adafruit.com/product/4410 | Required | Used indoors only.
 | 3W, 3.5MM PITCH TERM-BLOCK, SIDE | Circuit Board | DigiKey | ‎2073-TAD05-03-1-L-G-ND‎ |  | ‎TAD05-03-1-L-G‎ | 1 | $0.43 | 0 | $0.43 | $0.00

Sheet: Locked Decisions
Outdoor Cat Shelter Monitoring – Locked Decisions
Temperature probes: use Adafruit DS18B20 waterproof probes; pull-up resistor included (no separate resistor purchase needed).
Power
• Charging indoors only; no charging circuitry in field unit.
• Field operation uses swappable battery packs.
• Battery: 1S2P using 18650 cells (3.0–4.2 V system).
• USB-C is retained only for programming/debugging (not charging).
• NOTE: Selected Feather nRF52840 uses Micro-USB for programming; functionally equivalent to USB-C for this project.
Communications / Data Offload
• BLE offload to a phone is required from day one; app should download only new records since last offload.
Sensors / Connectors
• Waterproof temperature sensing required.
• DS18B20 waterproof probe acceptable.
• Connector requirement dropped; direct wiring is fine.
• Components tolerate Northeast US climate; sheltered from direct weather.
Suppliers / BOM Rules
• Prefer Adafruit first, Mouser second.
• BOM must use direct product links to unique SKUs (no search/category links).
• Include exact part numbers (MPNs), quantities, and flag long-lead/risk items.

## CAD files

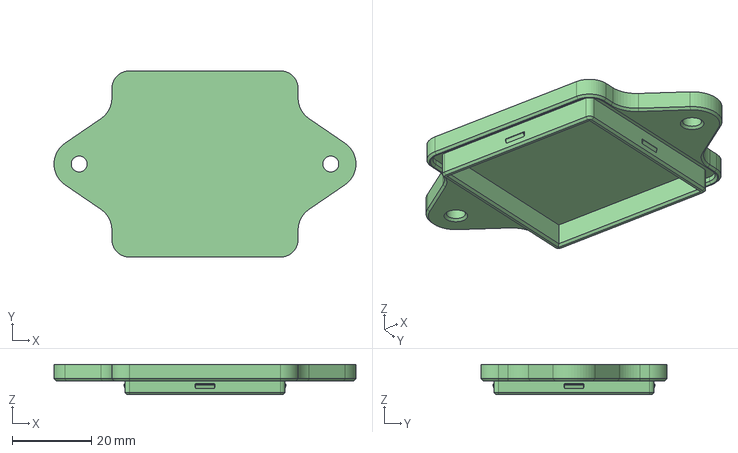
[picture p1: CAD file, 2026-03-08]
hardware/enclosure/AMG8833_Housing_Body - Cover.step
76.2 x 47.0 x 7.62 mm

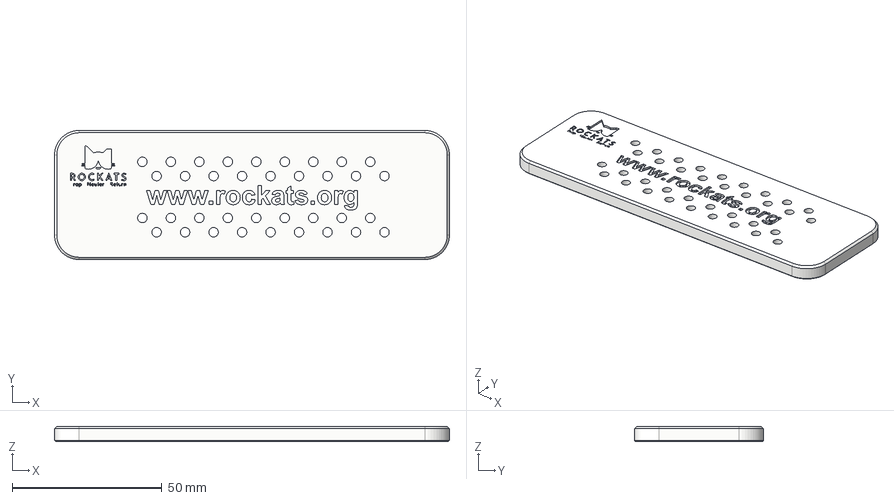
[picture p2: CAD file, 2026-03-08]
hardware/enclosure/Battery Charging Enclosure - Cover.step
132.1 x 43.2 x 5.08 mm
Charger Circuit Board
Battery Office Enclosure - Cover

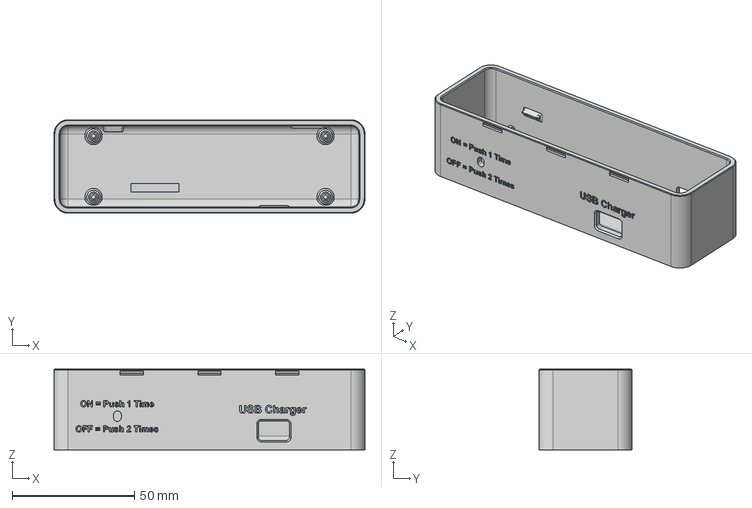
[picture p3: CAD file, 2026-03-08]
hardware/enclosure/Battery Charging Enclosure - Bottom.step
127.0 x 38.1 x 33.0 mm

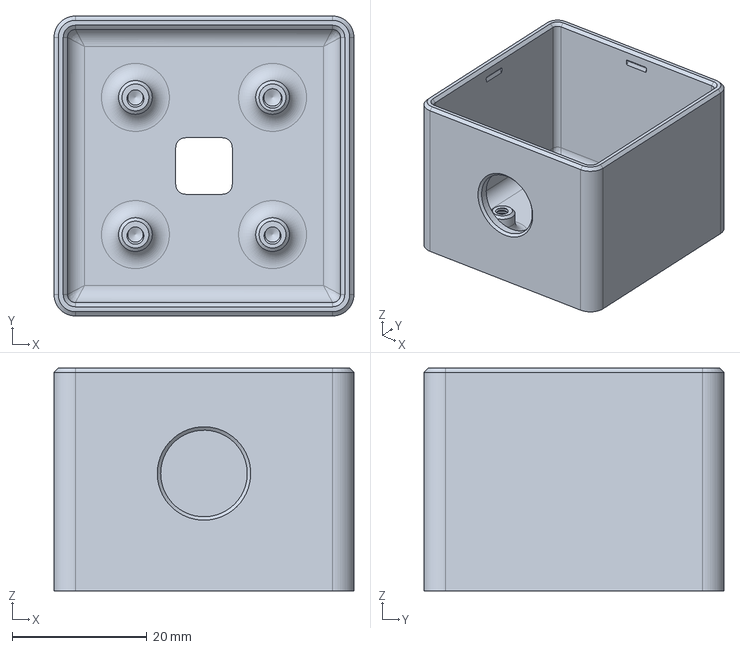
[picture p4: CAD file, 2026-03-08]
hardware/enclosure/AMG8833_Housing_Body.step
44.4 x 44.4 x 33.0 mm

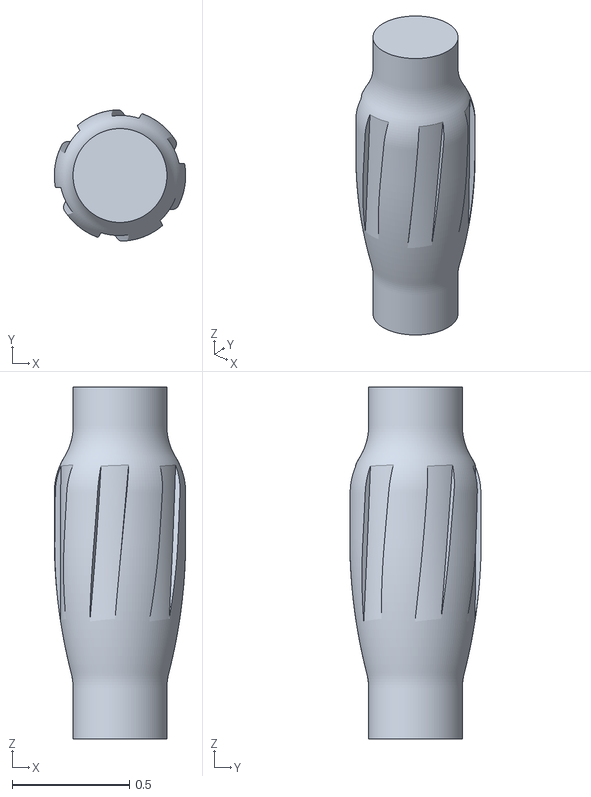
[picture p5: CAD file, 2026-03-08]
hardware/enclosure/Body1.stl
0.56 x 0.56 x 1.50

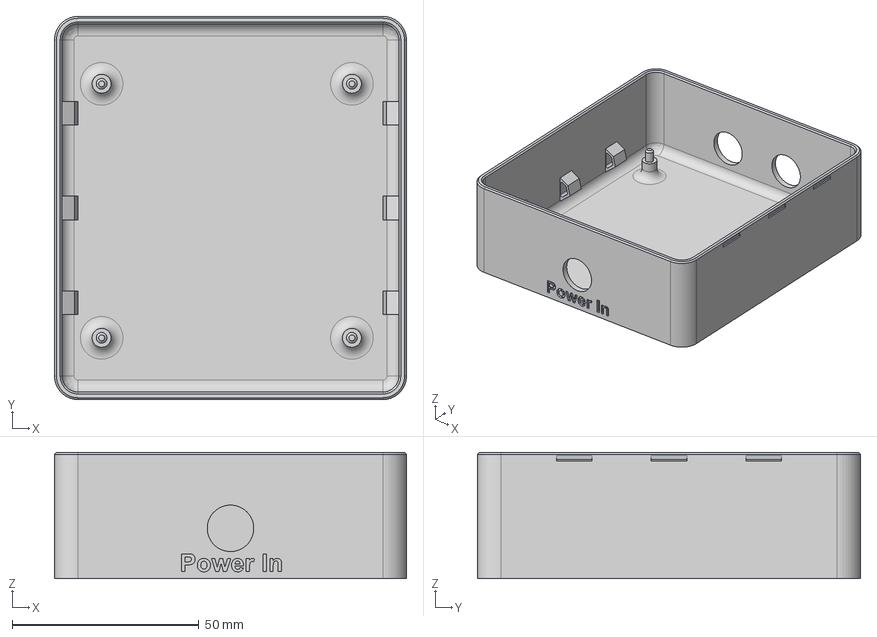
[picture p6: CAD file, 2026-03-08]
hardware/enclosure/Circuit Board Enclosure - Bottom.step
94.2 x 102.6 x 33.8 mm

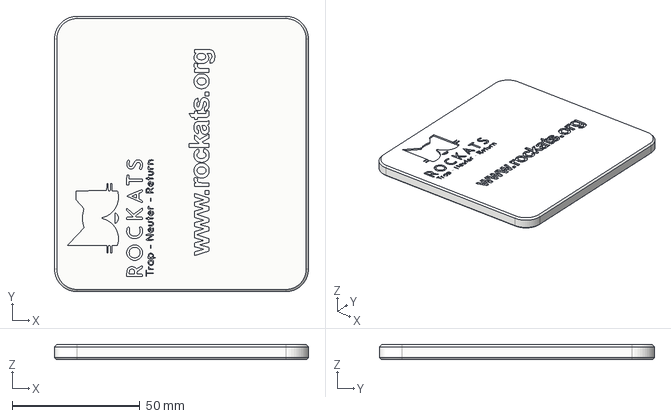
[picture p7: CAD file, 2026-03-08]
hardware/enclosure/Circuit Board Enclosure - Cover.step
99.3 x 107.7 x 5.72 mm

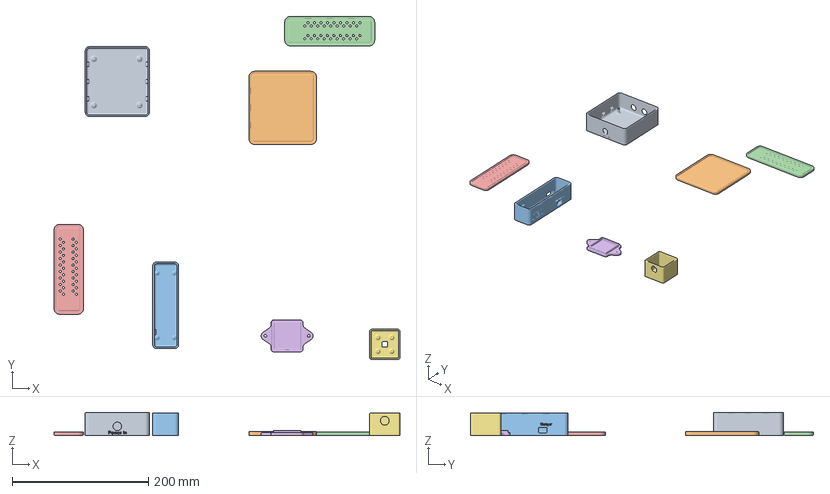
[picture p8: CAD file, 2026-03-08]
hardware/enclosure/Cat Shelter.3mf
507.4 x 503.1 x 33.8 mm
Circuit Board Enclosure - Bottom.step
Circuit Board Enclosure - Cover.step
Battery Charging Enclosure - Bottom.step
Battery Charging Enclosure - Cover.step
Battery Case Field - Cover.step
AMG8833_Housing_Body - Cover.step
AMG8833_Housing_Body.step

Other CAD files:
hardware/enclosure/Battery Case Field - Cover.step
hardware/enclosure/Circuit Board Enclosure - Bottom.3mf

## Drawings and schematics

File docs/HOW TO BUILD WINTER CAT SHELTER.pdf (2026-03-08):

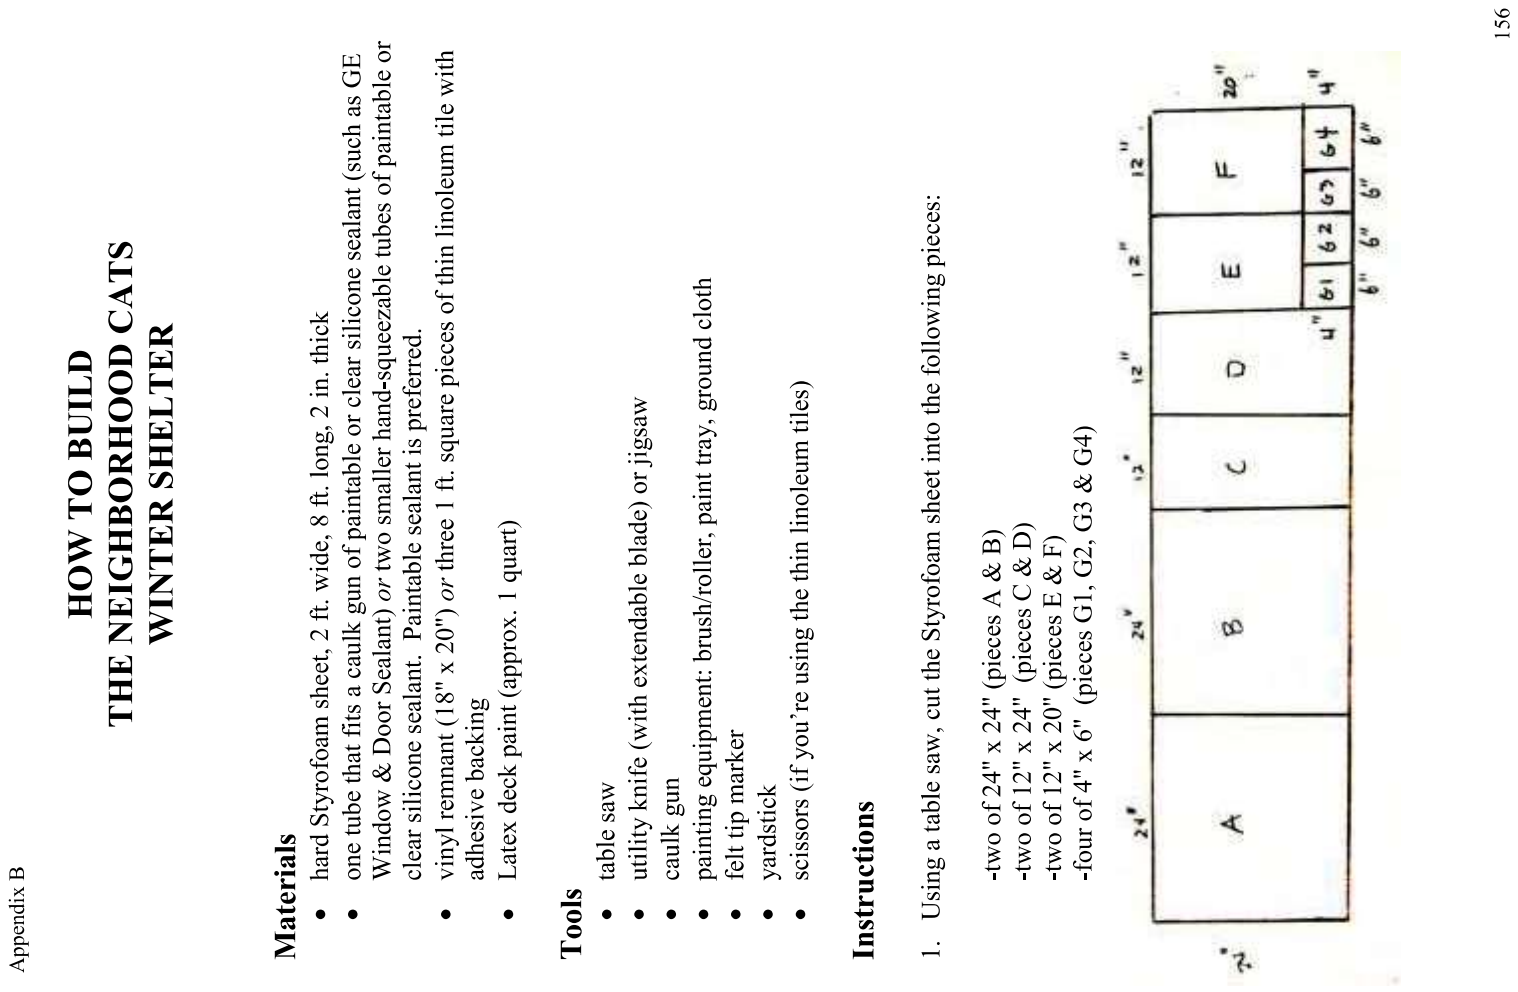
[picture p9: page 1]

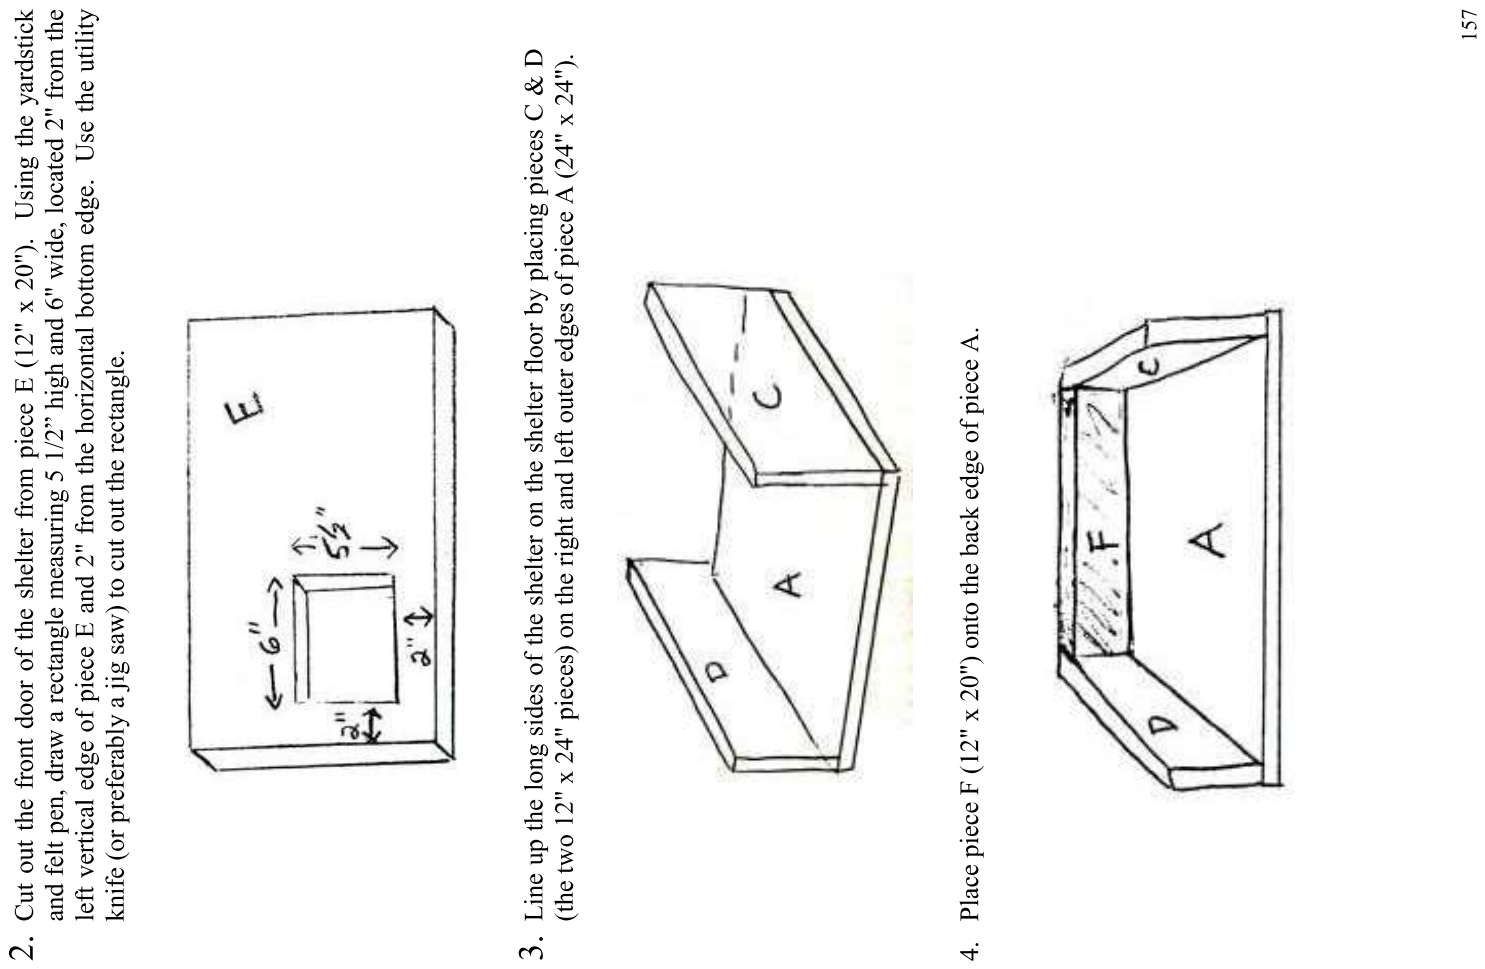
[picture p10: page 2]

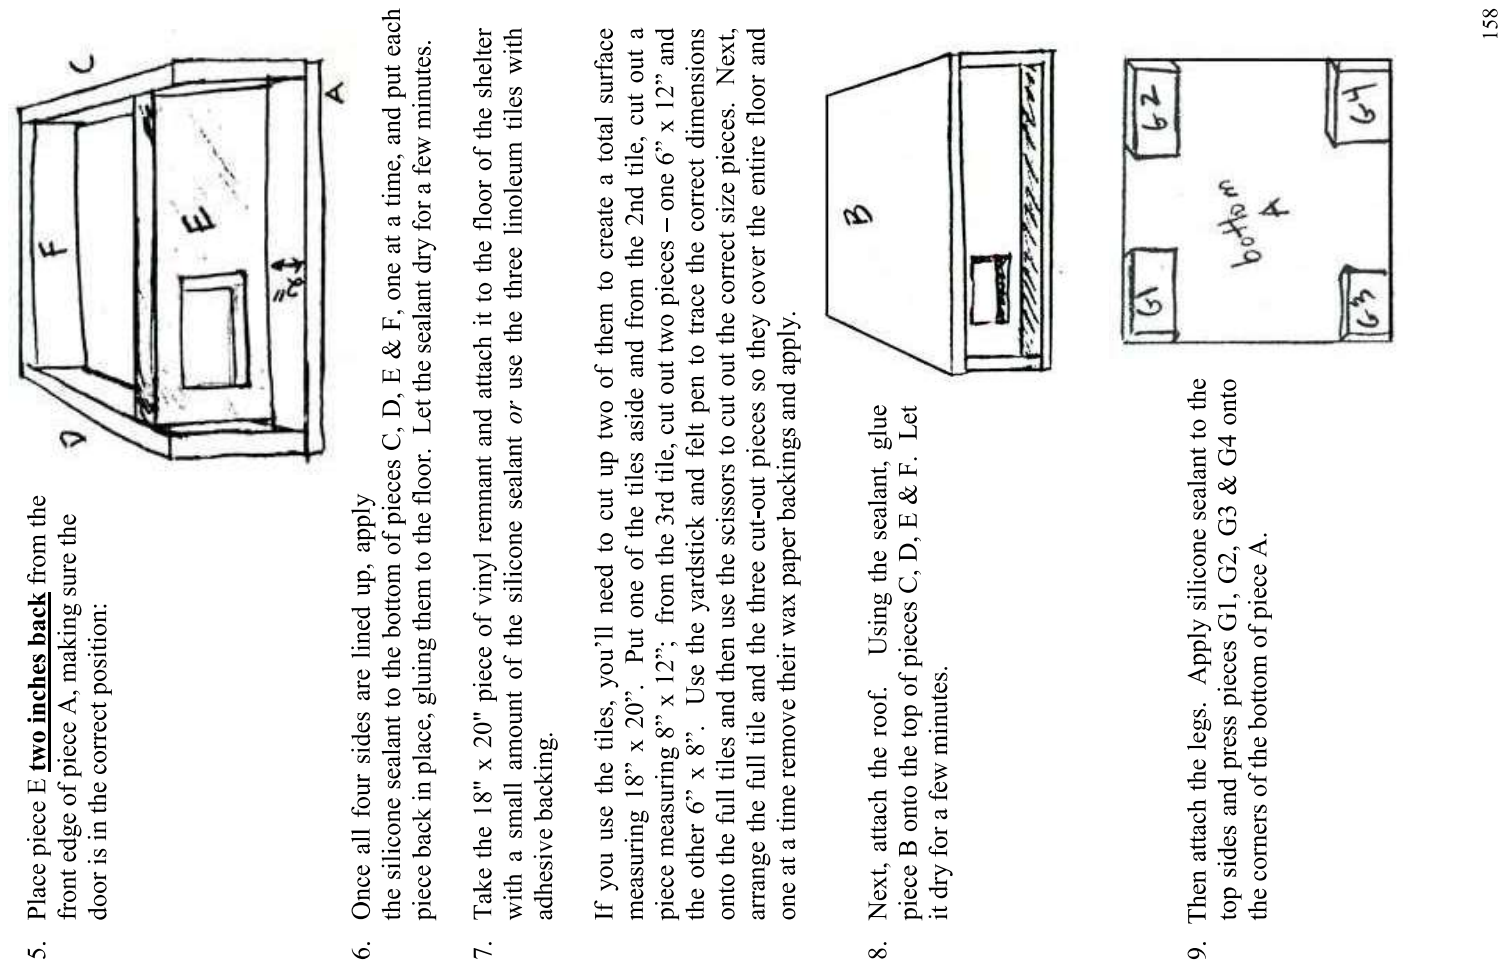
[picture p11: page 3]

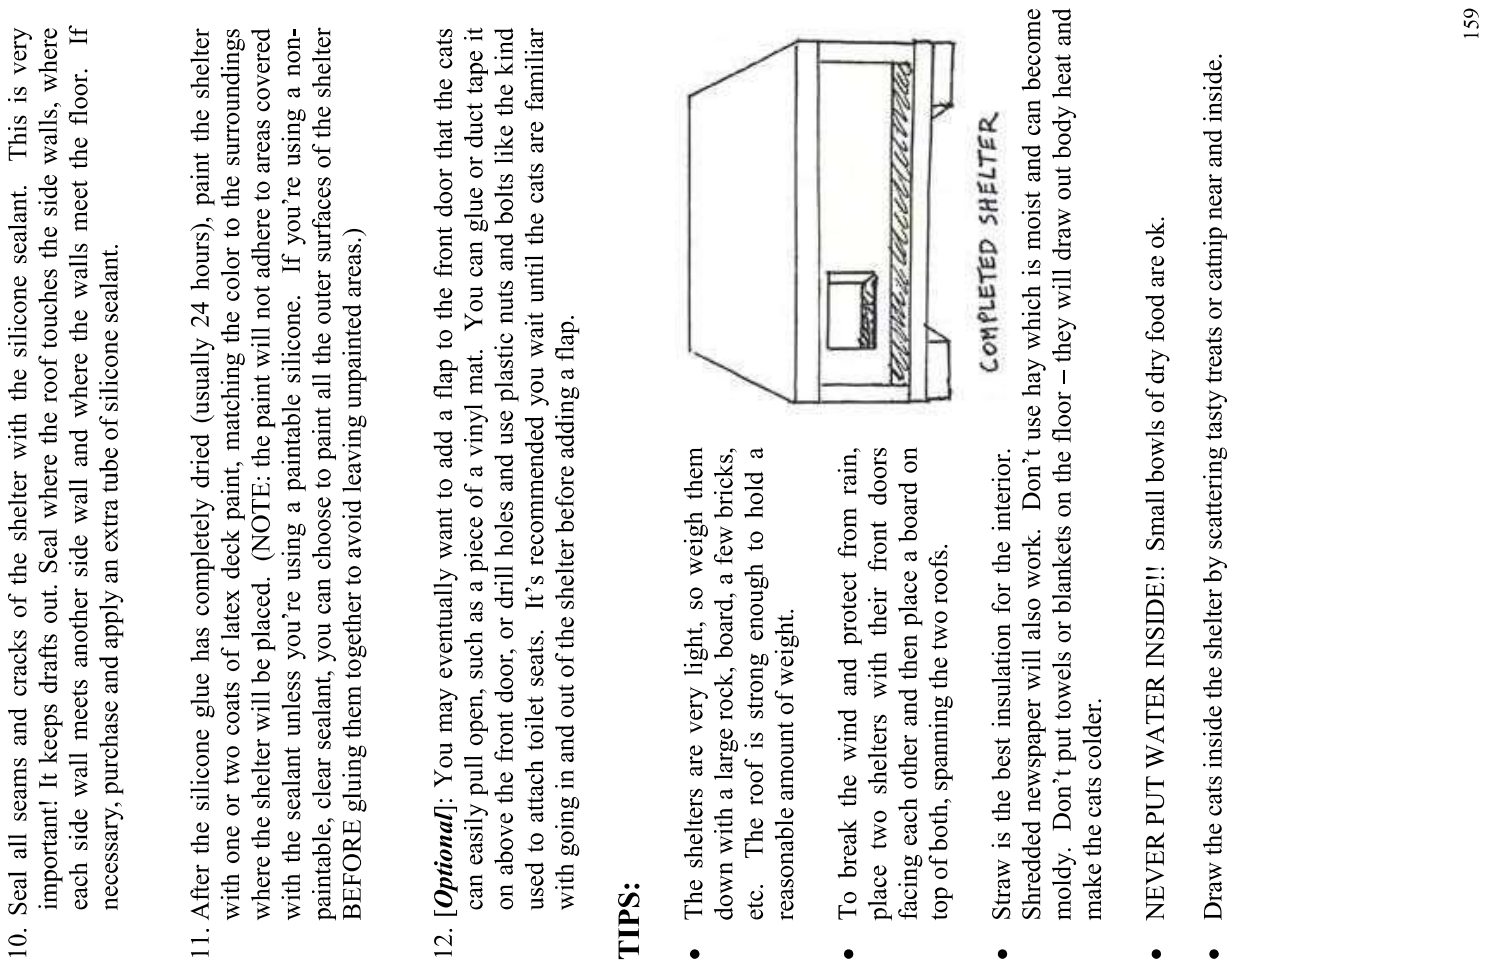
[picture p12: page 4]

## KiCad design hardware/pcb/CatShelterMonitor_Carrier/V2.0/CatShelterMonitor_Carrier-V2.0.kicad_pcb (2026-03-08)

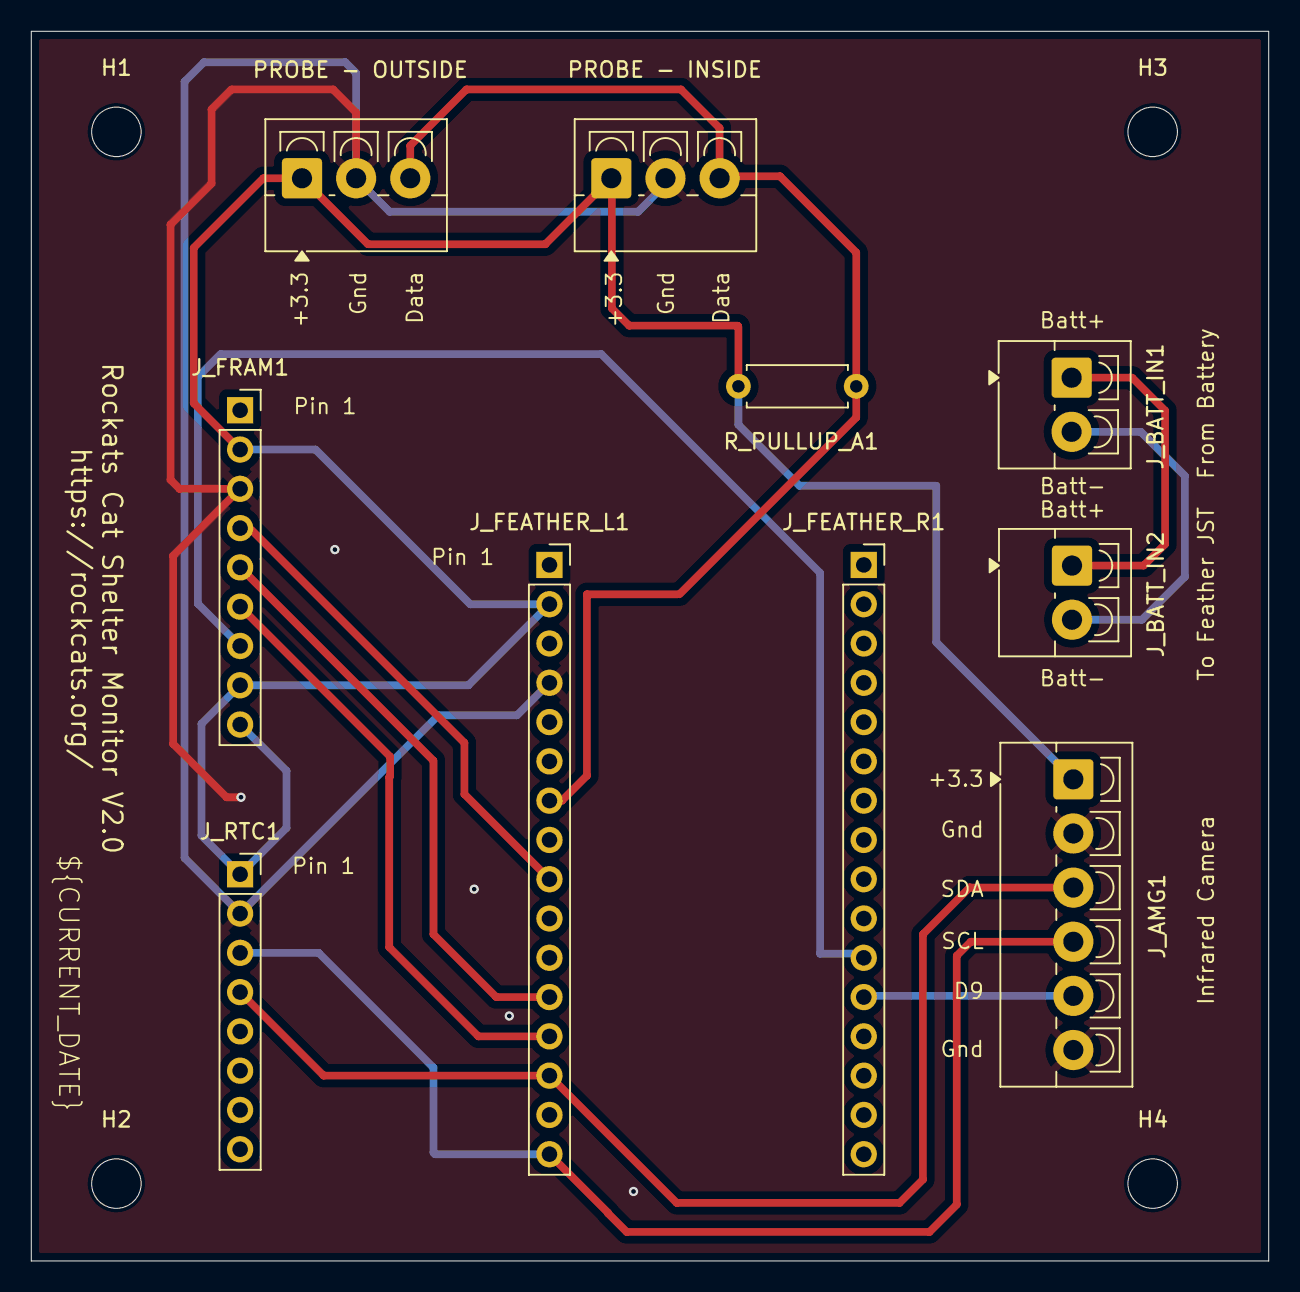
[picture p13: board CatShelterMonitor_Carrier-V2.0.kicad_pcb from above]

Board: 2 copper layers, 80.0 x 79.5 mm, 14 parts (0 on the bottom side), 12 nets.

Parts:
H1, H2, H3, H4: MountingHole_3.2mm_M3
J_AMG1: TerminalBlock_1x06_P3.5mm; TerminalBlock_4Ucon_1x06_P3.50mm_Vertical
J_BATT_IN1, J_BATT_IN2: J_BATT_OUT; TerminalBlock_4Ucon_1x02_P3.50mm_Vertical
J_FEATHER_L1: Conn_01x16; PinSocket_1x16_P2.54mm_Vertical
J_FEATHER_R1: Conn_01x16; PinSocket_1x16_P2.54mm_Vertical
J_FRAM1: Conn_01x09; PinSocket_1x09_P2.54mm_Vertical
J_RTC1: Conn_01x08; PinSocket_1x08_P2.54mm_Vertical
PROBE - INSIDE: Conn_01x03_Socket; TerminalBlock_4Ucon_1x03_P3.50mm_Vertical
PROBE - OUTSIDE: Conn_01x03_Socket; TerminalBlock_4Ucon_1x03_P3.50mm_Vertical
R_PULLUP_A1: 4.7k; R_Axial_DIN0207_L6.3mm_D2.5mm_P7.62mm_Horizontal

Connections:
+3V3: J_AMG1.1, J_FEATHER_L1.2, J_FRAM1.2, J_FRAM1.8, J_FRAM1.9, J_RTC1.1, PROBE - INSIDE.1, PROBE - OUTSIDE.1, R_PULLUP_A1.2
/A2_1WIRE: J_FEATHER_L1.7, PROBE - INSIDE.3, PROBE - OUTSIDE.3, R_PULLUP_A1.1
/AMG_INT_D9: J_AMG1.5, J_FEATHER_R1.12
/BATT+: J_BATT_IN1.1, J_BATT_IN2.1
/BATT-: J_BATT_IN1.2, J_BATT_IN2.2
/FRAM_CS_D10: J_FEATHER_R1.11, J_FRAM1.7
/I2C_SCL: J_AMG1.4, J_FEATHER_L1.16, J_RTC1.3
/I2C_SDA: J_AMG1.3, J_FEATHER_L1.14, J_RTC1.4
/SPI_MISO: J_FEATHER_L1.12, J_FRAM1.5
/SPI_MOSI: J_FEATHER_L1.13, J_FRAM1.6
/SPI_SCK: J_FEATHER_L1.9, J_FRAM1.4
GND: J_AMG1.2, J_AMG1.6, J_FEATHER_L1.4, J_FRAM1.3, J_RTC1.2, PROBE - INSIDE.2, PROBE - OUTSIDE.2

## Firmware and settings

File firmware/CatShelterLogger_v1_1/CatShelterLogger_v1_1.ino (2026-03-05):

/*

  Cat Shelter Monitor - v1.1 BLE Usability (RTC + FRAM + 2x DS18B20 + BLE CSV download)

  v1.1 additions:
  - Self-guided BLE output (banner/help on connect)
  - DOWNLOAD / DOWNLOADALL
  - Chunked CSV output with small delays to improve terminal reliability
  - STATUS command
  - SETUNIX <unix> command (phone sets time)

  NOTE (Demo Mode):
  - FRAM is currently offline (hardware wiring issue). This firmware supports RAM-only logging + download.

*/

#include <Arduino.h>
#include <Wire.h>
#include <RTClib.h>
#include <SPI.h>
#include <Adafruit_FRAM_SPI.h>
#include <OneWire.h>
#include <DallasTemperature.h>
#include <bluefruit.h>

// -------------------- Pins / Settings --------------------
static const uint8_t PIN_FRAM_CS   = 10;
static const uint8_t PIN_DS18B20   = A2;

// Logging interval (30 seconds)
static const uint32_t LOG_INTERVAL_MS = 30UL * 1000UL;

// FRAM sizing (won't be used if FRAM missing)
static const uint32_t FRAM_BYTES = 256UL * 1024UL;

static const uint32_t HDR_ADDR         = 0;
static const uint32_t HDR_SIZE         = 64;
static const uint32_t DATA_BASE_ADDR   = HDR_ADDR + HDR_SIZE;

static const uint32_t MAGIC = 0x43534C47; // 'CSLG'

// Packet/terminal pacing (helps some Android BLE terminals)
static const uint16_t CSV_LINE_DELAY_MS = 3;
static const uint16_t CSV_YIELD_EVERY_N_LINES = 25;
static const uint16_t CSV_YIELD_DELAY_MS = 20;

// -------------------- Data Structures --------------------
struct __attribute__((packed)) FramHeader {
  uint32_t magic;
  uint32_t write_index;
  uint32_t last_sent_index;
  uint32_t reserved[13];
};

struct __attribute__((packed)) Record {
  uint32_t ts;         // Unix time (seconds)
  int16_t  t0_c_x100;  // probe0 in C * 100
  int16_t  t1_c_x100;  // probe1 in C * 100
};

static const uint16_t RECORD_SIZE = sizeof(Record);

// -------------------- Globals --------------------
static uint32_t max_records = 0;

RTC_DS3231 rtc;
Adafruit_FRAM_SPI fram = Adafruit_FRAM_SPI(PIN_FRAM_CS, &SPI, 500000);

OneWire oneWire(PIN_DS18B20);
DallasTemperature ds18b20(&oneWire);

BLEUart bleuart;

FramHeader hdr;
uint32_t last_log_ms = 0;

static bool rtc_ok  = false;
static bool fram_ok = false;
static bool ram_only = false;

// RAM-only log buffer (demo mode)
// max_records is used as capacity; write_index counts entries in RAM too.
static Record* ram_records = nullptr;

// -------------------- Helpers --------------------
static float cFromX100(int16_t v) { return ((float)v) / 100.0f; }

static void blePrintln(const char* s) { bleuart.println(s); }

static void printWelcome() {
  blePrintln("CatShelterLogger v1.1");
  blePrintln("Type HELP for commands.");
}

static void printHelpV11() {
  blePrintln("Commands:");
  blePrintln("  HELP");
  blePrintln("  STATUS");
  blePrintln("  SETUNIX <unix_seconds>");
  blePrintln("  DOWNLOAD        (CSV since last_sent_index)");
  blePrintln("  DOWNLOADALL     (CSV all)");
  blePrintln("  CLEAR           (erase indexes / RAM buffer)");
}

// -------------------- FRAM helpers (no-op if FRAM missing) --------------------
static void framWriteBytes(uint32_t addr, const uint8_t* data, uint32_t len) {
  for (uint32_t i = 0; i < len; i++) fram.write8(addr + i, data[i]);
}

static void framReadBytes(uint32_t addr, uint8_t* data, uint32_t len) {
  for (uint32_t i = 0; i < len; i++) data[i] = fram.read8(addr + i);
}

static void saveHeader() {
  if (!fram_ok) return;
  framWriteBytes(HDR_ADDR, (uint8_t*)&hdr, sizeof(hdr));
}

static bool loadHeader() {
  if (!fram_ok) return false;
  FramHeader tmp;
  framReadBytes(HDR_ADDR, (uint8_t*)&tmp, sizeof(tmp));
  if (tmp.magic != MAGIC) return false;
  hdr = tmp;
  return true;
}

static void initFreshHeader() {
  memset(&hdr, 0, sizeof(hdr));
  hdr.magic = MAGIC;
  hdr.write_index = 0;
  hdr.last_sent_index = 0xFFFFFFFFUL;
  saveHeader();
}

static uint32_t recordAddr(uint32_t index) {
  return DATA_BASE_ADDR + index * RECORD_SIZE;
}

static bool writeRecord(uint32_t index, const Record& r) {
  if (!fram_ok) return false;
  if (index >= max_records) return false;
  framWriteBytes(recordAddr(index), (const uint8_t*)&r, sizeof(r));
  return true;
}

static bool readRecord(uint32_t index, Record& r) {
  if (!fram_ok) return false;
  if (index >= hdr.write_index) return false;
  framReadBytes(recordAddr(index), (uint8_t*)&r, sizeof(r));
  return true;
}

// -------------------- CSV Output --------------------
static void sendCsvHeader() {
  // Packet-safe CSV (keeps each row short enough for basic BLE terminal apps)
  // Format: MM/DD HH:MM,t0C,t1C   (Eastern Time; Celsius rounded to whole degrees)
  blePrintln("datetime,t0C,t1C");
  delay(200);
}

static void sendCsvRecordLine(const Record& r) {
  // Packet-safe, Excel-friendly timestamp + Celsius (rounded)
  // datetime = MM/DD HH:MM in Eastern Time (UTC-5) for the demo
  uint32_t ts = r.ts;
  if (ts >= 18000UL) ts -= 18000UL; // Eastern Standard Time (UTC-5). (No DST handling.)

  DateTime dt((uint32_t)ts);

  float t0c = cFromX100(r.t0_c_x100);
  float t1c = cFromX100(r.t1_c_x100);

  int t0i = (int)(t0c >= 0 ? (t0c + 0.5f) : (t0c - 0.5f));
  int t1i = (int)(t1c >= 0 ? (t1c + 0.5f) : (t1c - 0.5f));

  char line[32];
  // "02/21 16:19,-10,22" fits in a single BLE notification in most terminal apps
  snprintf(line, sizeof(line),
           "%02d/%02d %02d:%02d,%d,%d",
           dt.month(), dt.day(),
           dt.hour(), dt.minute(),
           t0i, t1i);

  bleuart.println(line);
}

// Send a CSV range in chunks with delays so some terminals don’t drop data.
// Returns number of records sent.
static uint32_t sendCsvRangeChunked(uint32_t startIndex, uint32_t endIndexInclusive) {
  if (endIndexInclusive < startIndex) return 0;

  uint32_t sent = 0;
  for (uint32_t i = startIndex; i <= endIndexInclusive; i++) {
    Record r;

    if (ram_only) {
      if (i >= hdr.write_index) break;
      r = ram_records[i];
    } else {
      if (!readRecord(i, r)) break;
    }

    sendCsvRecordLine(r);
    sent++;

    delay(CSV_LINE_DELAY_MS);
    if ((sent % CSV_YIELD_EVERY_N_LINES) == 0) delay(CSV_YIELD_DELAY_MS);
  }
  return sent;
}

// -------------------- Commands --------------------
static void doStatus() {
  bleuart.print("fw_build=");
  bleuart.print(__DATE__);
  bleuart.print(" ");
  bleuart.println(__TIME__);

  bleuart.print("write_index=");
  bleuart.println(hdr.write_index);

  bleuart.print("last_sent_index=");
  bleuart.println(hdr.last_sent_index);

  bleuart.print("max_records=");
  bleuart.println(max_records);

  bleuart.print("fram_ok=");
  bleuart.println(fram_ok ? 1 : 0);

  bleuart.print("rtc_ok=");
  bleuart.println(rtc_ok ? 1 : 0);

  bleuart.print("ram_only=");
  bleuart.println(ram_only ? 1 : 0);
}

static void doClear() {
  hdr.write_index = 0;
  hdr.last_sent_index = 0xFFFFFFFFUL;

  if (ram_only && ram_records) {
    // Optional: not necessary to erase contents
  }

  saveHeader();
  blePrintln("OK: CLEARED");
}

static void doSetUnix(uint32_t unix_ts) {
  // For demo: even if RTC is not wired, we still accept and use unix_ts for logging
  rtc_ok = false; // physical RTC may be broken

  // If RTClib RTC is available, we *could* attempt rtc.adjust(...)
  // but your RTC is known bad for the demo, so we rely on stored unix_ts per record.

  // We don't store a global; we just use millis-based + last known unix in the logger loop.
  // We'll set "time base" variables used in loop().
  // (These are declared below.)
  extern uint32_t g_phone_unix_base;
  extern uint32_t g_phone_millis_base;

  g_phone_unix_base = unix_ts;
  g_phone_millis_base = millis();

  blePrintln("OK: PHONE TIME SET");
}

static void doDownloadNew() {
  if (hdr.write_index == 0) {
    blePrintln("DOWNLOAD_COMPLETE,0,0");
    return;
  }

  sendCsvHeader();

  uint32_t start = (hdr.last_sent_index == 0xFFFFFFFFUL) ? 0 : (hdr.last_sent_index + 1);
  if (start >= hdr.write_index) {
    blePrintln("DOWNLOAD_COMPLETE,0,0");
    return;
  }

  uint32_t end = hdr.write_index - 1;
  uint32_t sent = sendCsvRangeChunked(start, end);

  hdr.last_sent_index = end;
  saveHeader();

  bleuart.print("DOWNLOAD_COMPLETE,");
  bleuart.print(sent);
  bleuart.println(",0");
}

static void doDownloadAll() {
  if (hdr.write_index == 0) {
    blePrintln("DOWNLOAD_COMPLETE,0,0");
    return;
  }

  sendCsvHeader();

  uint32_t sent = sendCsvRangeChunked(0, hdr.write_index - 1);

  hdr.last_sent_index = hdr.write_index - 1;
  saveHeader();

  bleuart.print("DOWNLOAD_COMPLETE,");
  bleuart.print(sent);
  bleuart.println(",0");
}

static void handleCommand(String cmd) {
  cmd.trim();
  cmd.toUpperCase();

  if (cmd == "HELP" || cmd == "H") {
    printHelpV11();
    return;
  }
  if (cmd == "STATUS") {
    doStatus();
    return;
  }
  if (cmd == "CLEAR") {
    doClear();
    return;
  }
  if (cmd == "DOWNLOAD") {
    doDownloadNew();
    return;
  }
  if (cmd == "DOWNLOADALL") {
    doDownloadAll();
    return;
  }

  if (cmd.startsWith("SETUNIX")) {
    // SETUNIX <unix>
    int sp = cmd.indexOf(' ');
    if (sp < 0) {
      blePrintln("ERR: usage SETUNIX <unix>");
      return;
    }
    String val = cmd.substring(sp + 1);
    val.trim();
    uint32_t t = (uint32_t)val.toInt();
    doSetUnix(t);
    return;
  }

  blePrintln("Unknown command. Type HELP");
}

// -------------------- BLE Callbacks --------------------
void connect_callback(uint16_t conn_handle) {
  (void)conn_handle;
  printWelcome();
}

void disconnect_callback(uint16_t conn_handle, uint8_t reason) {
  (void)conn_handle;
  (void)reason;
}

// -------------------- Time base (phone-set unix) --------------------
uint32_t g_phone_unix_base = 0;
uint32_t g_phone_millis_base = 0;

// Compute current unix from phone base + millis delta.
// If phone time not set yet, returns 0.
static uint32_t currentUnixFromPhone() {
  if (g_phone_unix_base == 0) return 0;
  uint32_t dt_ms = millis() - g_phone_millis_base;
  return g_phone_unix_base + (dt_ms / 1000UL);
}

// -------------------- Logging --------------------
static void ensureRamBuffer() {
  if (ram_records) return;

  // Capacity target: 30 sec logging, up to ~2 days is 5760 records/day => 11520 for ~2 days
  // You currently show max_records=11520 in status; keep that.
  if (max_records == 0) max_records = 11520;

  ram_records = (Record*)malloc(max_records * sizeof(Record));
  if (!ram_records) {
    // If malloc fails, reduce capacity
    max_records = 5760; // ~1 day @ 30s
    ram_records = (Record*)malloc(max_records * sizeof(Record));
  }
}

static void doLogOnce() {
  if (max_records == 0) return;

  if (hdr.write_index >= max_records) {
    // Buffer full
    return;
  }

  ds18b20.requestTemperatures();
  float t0 = ds18b20.getTempCByIndex(0);
  float t1 = ds18b20.getTempCByIndex(1);

  // Store as x100
  int16_t t0_x100 = (int16_t)(t0 * 100.0f);
  int16_t t1_x100 = (int16_t)(t1 * 100.0f);

  Record r;
  r.ts = currentUnixFromPhone(); // may be 0 until SETUNIX is done
  r.t0_c_x100 = t0_x100;
  r.t1_c_x100 = t1_x100;

  if (ram_only) {
    ensureRamBuffer();
    if (ram_records) {
      ram_records[hdr.write_index] = r;
      hdr.write_index++;
    }
    return;
  }

  // FRAM mode
  if (!fram_ok) return;

  if (hdr.write_index >= max_records) return;
  if (!writeRecord(hdr.write_index, r)) return;

  hdr.write_index++;
  saveHeader();
}

// -------------------- Setup / Loop --------------------
void setup() {
  Serial.begin(115200);
  delay(200);

  // Try FRAM
  SPI.begin();
  fram_ok = fram.begin();

  // Try RTC (known bad for demo)
  Wire.begin();
  rtc_ok = rtc.begin();

  // Compute FRAM max_records if FRAM present
  if (fram_ok) {
    uint32_t usable = FRAM_BYTES - DATA_BASE_ADDR;
    max_records = usable / RECORD_SIZE;

    if (!loadHeader()) {
      initFreshHeader();
    }
  } else {
    // Demo RAM-only mode
    ram_only = true;
    max_records = 11520; // ~2 days @ 30 sec
    initFreshHeader();   // keep hdr sane
    ensureRamBuffer();
  }

  // DS18B20
  ds18b20.begin();
  ds18b20.setWaitForConversion(true);

  // BLE
  Bluefruit.begin();
  Bluefruit.setTxPower(4);
  Bluefruit.setName("CatSh");

  Bluefruit.Periph.setConnectCallback(connect_callback);
  Bluefruit.Periph.setDisconnectCallback(disconnect_callback);

  bleuart.begin();

  // Advertising
  Bluefruit.Advertising.addFlags(BLE_GAP_ADV_FLAGS_LE_ONLY_GENERAL_DISC_MODE);
  Bluefruit.Advertising.addTxPower();
  Bluefruit.Advertising.addService(bleuart);
  Bluefruit.Advertising.addName();

  Bluefruit.Advertising.restartOnDisconnect(true);
  Bluefruit.Advertising.setInterval(32, 244);
  Bluefruit.Advertising.setFastTimeout(30);
  Bluefruit.Advertising.start(0);
}

void loop() {
  // Logging timer
  uint32_t now = millis();
  if ((now - last_log_ms) >= LOG_INTERVAL_MS) {
    last_log_ms = now;
    doLogOnce();
  }

  // BLE command handling
  if (bleuart.available()) {
    String cmd = bleuart.readStringUntil('\n');
    cmd.trim();
    if (cmd.length() > 0) handleCommand(cmd);
  }
}

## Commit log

2026-01-16 Baseline: hardware verified + firmware v1.0
    [Cat_Shelter_BOM_v4.xlsx]
2026-03-05 Cat Shelter: finalize field battery enclosure wiring (B+/B-, P+/P-, RUEF110 fuse, 3ft 22AWG cable)
2026-03-05 PCB RevB: add KiCad project files (carrier schematic + PCB)
    [CatShelterMonitor_Carrier-RevB.kicad_pcb, CatShelterMonitor_Carrier-RevB.kicad_sch]
2026-03-05 Cat Shelter: update BOM v4 and v1.1 firmware
    [Cat_Shelter_BOM_v4.xlsx]
2026-03-08 Add updated CatShelter documentation, BOM v2, enclosure CAD models, and PlatformIO project structure
    [AMG8833_Housing_Body - Cover.step, AMG8833_Housing_Body.step, Battery Case Field - Cover.step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]
2026-03-08 Improve .gitignore for KiCad, PlatformIO, and editor artifacts
2026-03-08 Update .gitignore to ignore KiCad backups and development artifacts
2026-03-08 Add CatShelterMonitor Carrier PCB V2.0 and RevC variants
    [CatShelterMonitor_Carrier-RevC_RJ45.kicad_pcb, CatShelterMonitor_Carrier-RevC_RJ45.kicad_sch, CatShelterMonitor_Carrier-RevC_TerminalBlock.kicad_sch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]
2026-03-08 Reorganize CatShelter carrier PCB repo structure
    [CatShelterMonitor_Carrier-RevB.kicad_pcb, CatShelterMonitor_Carrier-RevB.kicad_sch, CatShelterMonitor_Carrier-RevC_RJ45.kicad_pcb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]
2026-03-09 Organize hardware assets into enclosure and datasheet folders
    [AMG8833_Housing_Body - Cover.step, AMG8833_Housing_Body.step, Battery Case Field - Cover.step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]
2026-03-11 Fix firmware folder structure for CatShelterLogger_v1_0
    [CatShelterLogger_v1_0.ino]
